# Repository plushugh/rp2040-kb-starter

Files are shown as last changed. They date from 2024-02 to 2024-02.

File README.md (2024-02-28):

# A Keyboard PCB Starter for the RaspberrySilicon RP2040 Microcontroller

## KiCad Requirements

I recommend KiCad version >= 8.0, and make sure you install the
[kiswitch](https://github.com/kiswitch/kiswitch) plugin (Version 2.4)
from the `Plugin and Content Manager`

I also recommend installing the kbplacer plugin for easy alignment of switch footprints

## Credits

Inspired by [Sleepdealr/RP2040-designguide](https://github.com/Sleepdealr/RP2040-designguide?tab=readme-ov-file)

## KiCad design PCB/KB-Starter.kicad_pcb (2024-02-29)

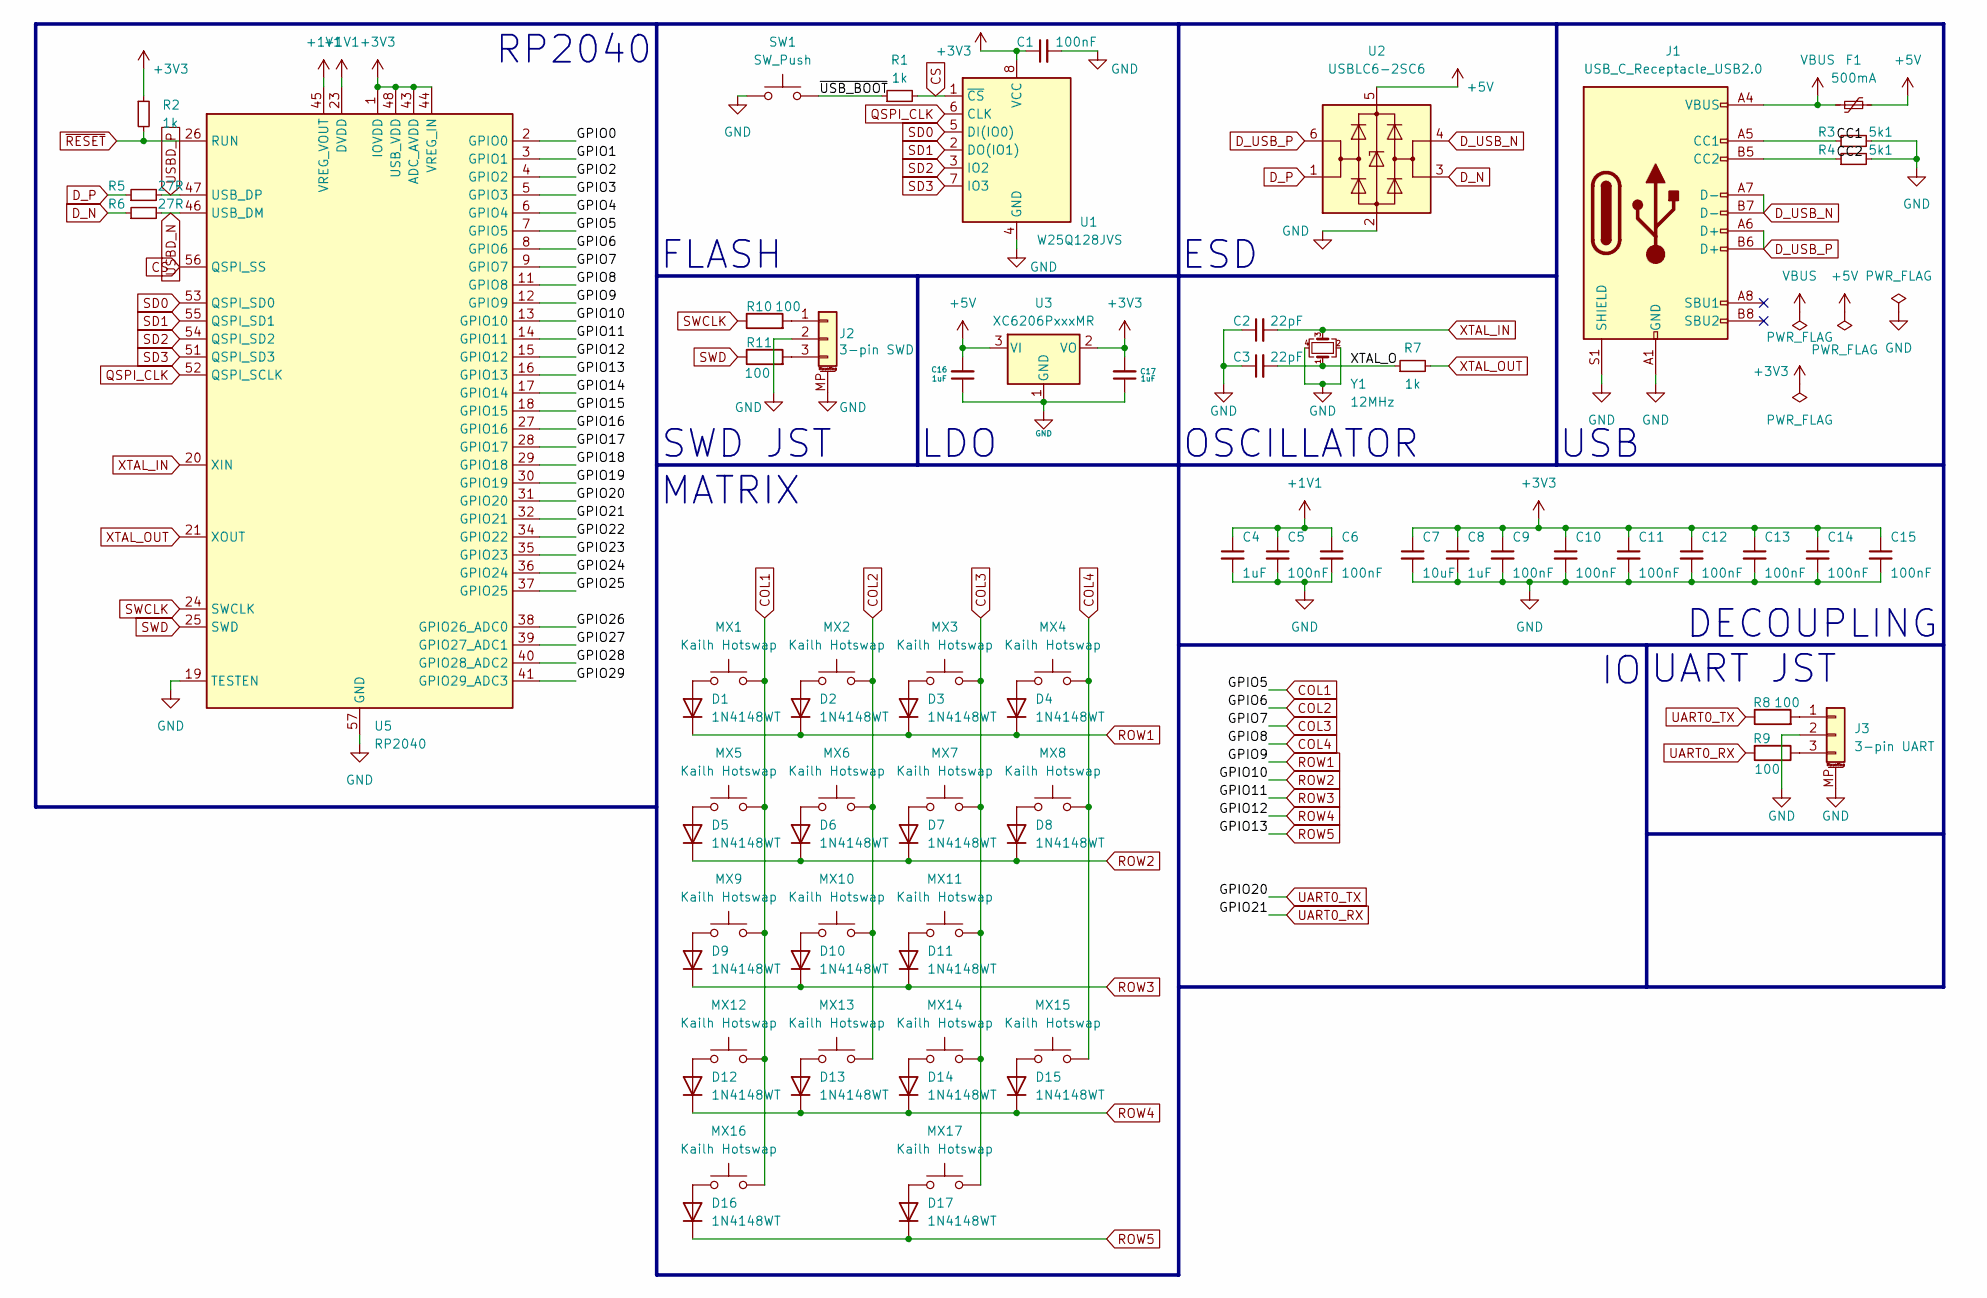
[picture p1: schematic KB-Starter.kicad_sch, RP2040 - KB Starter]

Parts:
C1, C5, C6, C9, C10, C11, C12, C13, C14, C15: 100nF; C_0402_1005Metric; LCSC C1525
C2, C3: 22pF; C_0402_1005Metric; LCSC C1555
C4, C8, C16, C17: 1uF; C_0402_1005Metric; LCSC C52923
C7: 10uF; C_0402_1005Metric; LCSC C15525
D1, D2, D3, D4, D5, D6, D7, D8, D9, D10, D11, D12, D13, D14, D15, D16, D17: 1N4148WT; D_SOD-523; LCSC C727112
F1: 500mA; Fuse_1206_3216Metric; LCSC C70076
J1: USB_C_Receptacle_USB2.0; USB_C_Receptacle_HRO_TYPE-C-31-M-12; LCSC C165948
J2: 3-pin SWD; JST_SH_BM03B-SRSS-TB_1x03-1MP_P1.00mm_Vertical
J3: 3-pin UART; JST_SH_BM03B-SRSS-TB_1x03-1MP_P1.00mm_Vertical
MX1, MX2, MX3, MX4, MX5, MX6, MX7, MX8, MX9, MX10, MX11, MX12, MX13, MX14, MX15, MX16, MX17: Kailh Hotswap; SW_Hotswap_Kailh_MX_1.00u; LCSC C5156480
R1, R2, R7: 1k; R_0402_1005Metric; LCSC C11702
R3, R4: 5k1; R_0402_1005Metric; LCSC C25905
R5, R6: 27R; R_0603_1608Metric; LCSC C25190
R8, R9, R10, R11: 100; R_0603_1608Metric
SW1: SW_Push; SW_SPST_PTS810; LCSC C221896
U1: W25Q128JVS; SOIC-8_5.23x5.23mm_P1.27mm; LCSC C131025
U2: USBLC6-2SC6; SOT-23-6; LCSC C2827654
U3: XC6206PxxxMR; SOT-23-3; LCSC C5250982
U5: RP2040; QFN-56-1EP_7x7mm_P0.4mm_EP3.2x3.2mm; LCSC C2040
Y1: 12MHz; Crystal_SMD_3225-4Pin_3.2x2.5mm; LCSC C9002

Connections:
+1V1: C4.1, C5.1, C6.1, U5.23 (DVDD), U5.45 (VREG_VOUT), U5.50 (DVDD)
+3V3: C1.1, C7.1, C8.1, C9.1, C10.1, C11.1, C12.1, C13.1, C14.1, C15.1, C17.2, R2.1, U1.8 (VCC), U3.2 (VO), U5.1 (IOVDD), U5.10 (IOVDD), U5.22 (IOVDD), U5.33 (IOVDD), U5.42 (IOVDD), U5.43 (ADC_AVDD), U5.44 (VREG_IN), U5.48 (USB_VDD), U5.49 (IOVDD)
+5V: C16.2, F1.2, U2.5 (VBUS), U3.3 (VI)
/CC1: J1.A5 (CC1), R3.1
/CC2: J1.B5 (CC2), R4.1
/GPIO0: U5.2 (GPIO0)
/GPIO1: U5.3 (GPIO1)
/GPIO2: U5.4 (GPIO2)
/GPIO3: U5.5 (GPIO3)
/GPIO4: U5.6 (GPIO4)
/GPIO14: U5.17 (GPIO14)
/GPIO15: U5.18 (GPIO15)
/GPIO16: U5.27 (GPIO16)
/GPIO17: U5.28 (GPIO17)
/GPIO18: U5.29 (GPIO18)
/GPIO19: U5.30 (GPIO19)
/GPIO22: U5.34 (GPIO22)
/GPIO23: U5.35 (GPIO23)
/GPIO24: U5.36 (GPIO24)
/GPIO25: U5.37 (GPIO25)
/GPIO26: U5.38 (GPIO26_ADC0)
/GPIO27: U5.39 (GPIO27_ADC1)
/GPIO28: U5.40 (GPIO28_ADC2)
/GPIO29: U5.41 (GPIO29_ADC3)
/XTAL_O: C3.2, R7.1, Y1.1
/~USB_BOOT: R1.1, SW1.2
COL1: MX1.2, MX5.2, MX9.2, MX12.2, MX16.2, U5.7 (GPIO5)
COL2: MX2.2, MX6.2, MX10.2, MX13.2, U5.8 (GPIO6)
COL3: MX3.2, MX7.2, MX11.2, MX14.2, MX17.2, U5.9 (GPIO7)
COL4: MX4.2, MX8.2, MX15.2, U5.11 (GPIO8)
CS: R1.2, U1.1 (~CS), U5.56 (QSPI_SS)
D_N: R6.1, U2.3 (I/O2)
D_P: R5.1, U2.1 (I/O1)
D_USB_N: J1.A7 (D-), J1.B7 (D-), U2.4 (I/O2)
D_USB_P: J1.A6 (D+), J1.B6 (D+), U2.6 (I/O1)
GND: C1.2, C2.1, C3.1, C4.2, C5.2, C6.2, C7.2, C8.2, C9.2, C10.2, C11.2, C12.2, C13.2, C14.2, C15.2, C16.1, C17.1, J1.A1 (GND), J1.A12 (GND), J1.B1 (GND), J1.B12 (GND), J1.S1 (SHIELD), J2.2, J2.MP (MountPin), J3.2, J3.MP (MountPin), R3.2, R4.2, SW1.1, U1.4 (GND), U2.2 (GND), U3.1 (GND), U5.19 (TESTEN), U5.57 (GND), Y1.2, Y1.4
unnamed: D1.2 (A), MX1.1
unnamed: D2.2 (A), MX2.1
unnamed: D3.2 (A), MX3.1
unnamed: D4.2 (A), MX4.1
unnamed: D5.2 (A), MX5.1
unnamed: D6.2 (A), MX6.1
unnamed: D7.2 (A), MX7.1
unnamed: D8.2 (A), MX8.1
unnamed: D9.2 (A), MX9.1
unnamed: D10.2 (A), MX10.1
unnamed: D11.2 (A), MX11.1
unnamed: D12.2 (A), MX12.1
unnamed: D13.2 (A), MX13.1
unnamed: D14.2 (A), MX14.1
unnamed: D15.2 (A), MX15.1
unnamed: D16.2 (A), MX16.1
unnamed: D17.2 (A), MX17.1
unnamed: J2.1, R10.2
unnamed: J2.3, R11.2
unnamed: J3.1, R8.2
unnamed: J3.3, R9.1
QSPI_CLK: U1.6 (CLK), U5.52 (QSPI_SCLK)
ROW1: D1.1 (K), D2.1 (K), D3.1 (K), D4.1 (K), U5.12 (GPIO9)
ROW2: D5.1 (K), D6.1 (K), D7.1 (K), D8.1 (K), U5.13 (GPIO10)
ROW3: D9.1 (K), D10.1 (K), D11.1 (K), U5.14 (GPIO11)
ROW4: D12.1 (K), D13.1 (K), D14.1 (K), D15.1 (K), U5.15 (GPIO12)
ROW5: D16.1 (K), D17.1 (K), U5.16 (GPIO13)
SD0: U1.5 (DI(IO0)), U5.53 (QSPI_SD0)
SD1: U1.2 (DO(IO1)), U5.55 (QSPI_SD1)
SD2: U1.3 (IO2), U5.54 (QSPI_SD2)
SD3: U1.7 (IO3), U5.51 (QSPI_SD3)
SWCLK: R10.1, U5.24 (SWCLK)
SWD: R11.1, U5.25 (SWD)
UART0_RX: R9.2, U5.32 (GPIO21)
UART0_TX: R8.1, U5.31 (GPIO20)
USBD_N: R6.2, U5.46 (USB_DM)
USBD_P: R5.2, U5.47 (USB_DP)
VBUS: F1.1, J1.A4 (VBUS), J1.A9 (VBUS), J1.B4 (VBUS), J1.B9 (VBUS)
XTAL_IN: C2.2, U5.20 (XIN), Y1.3
XTAL_OUT: R7.2, U5.21 (XOUT)
~RESET: R2.2, U5.26 (RUN)

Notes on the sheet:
MATRIX
ESD
UART JST
DECOUPLING
OSCILLATOR
USB
LDO
SWD JST
RP2040
FLASH

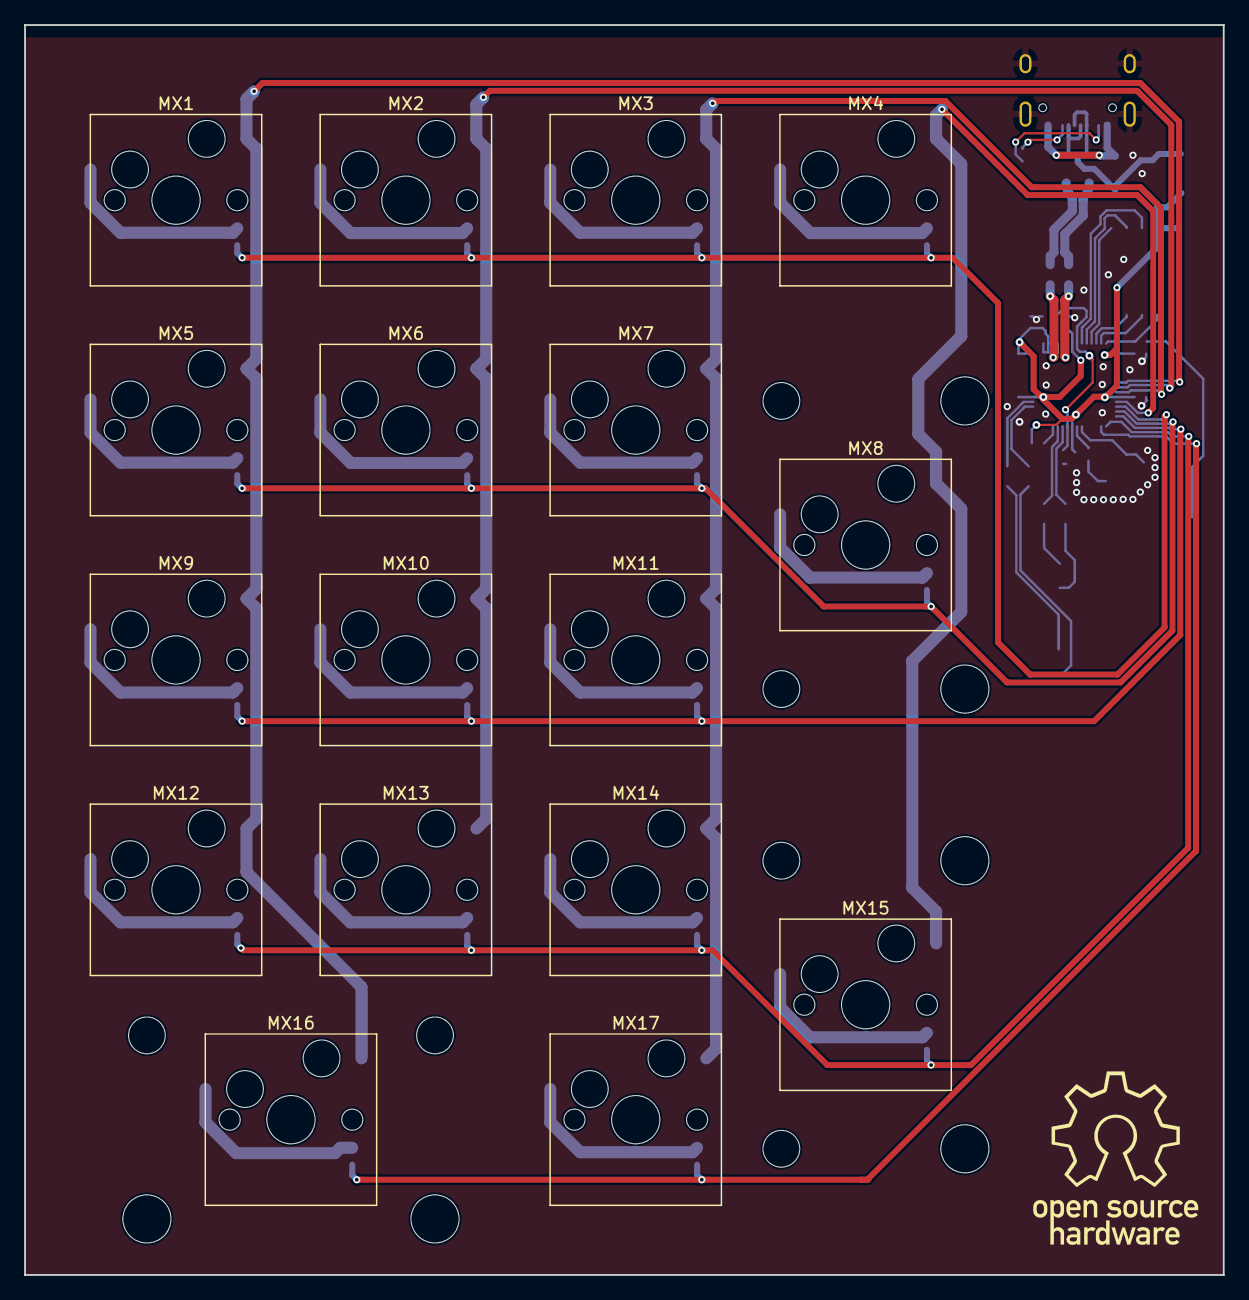
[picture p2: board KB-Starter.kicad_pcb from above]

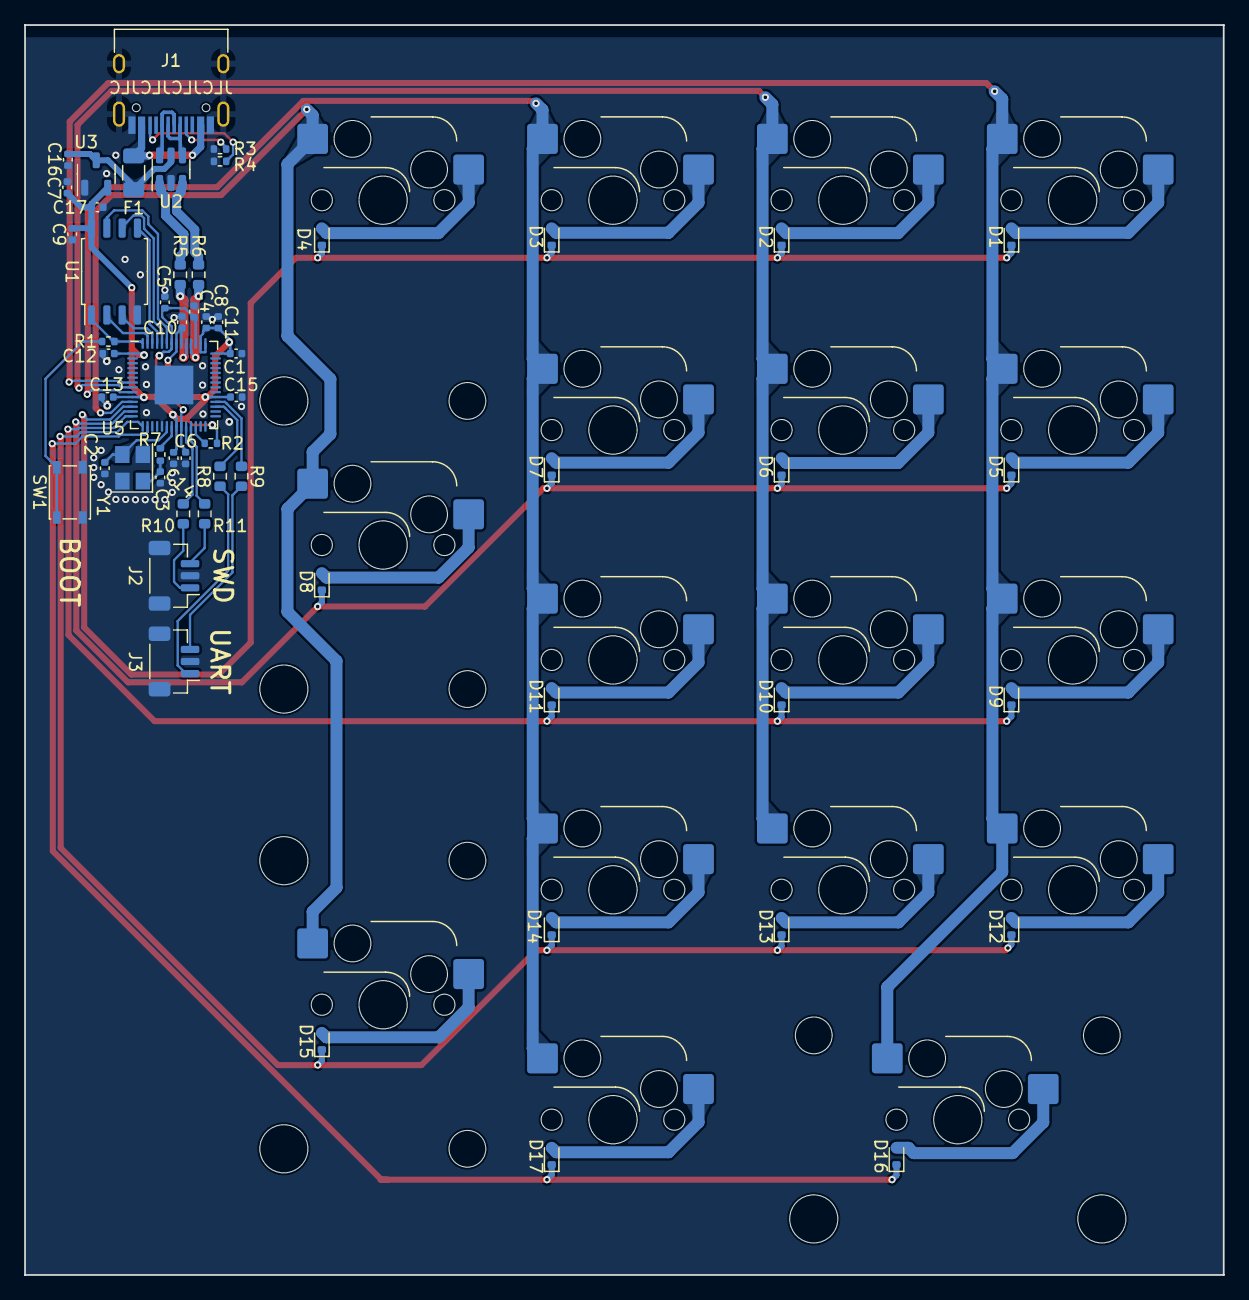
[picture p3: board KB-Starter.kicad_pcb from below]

Board: 2 copper layers, 99.3 x 103.6 mm, 75 parts (55 on the bottom side), 58 nets.

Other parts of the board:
STAB1, STAB2, STAB3: Stabilizer_Cherry_MX_2.00u

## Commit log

2024-02-13 init: basic mcu setup
    [KB-Starter.kicad_pcb, KB-Starter.kicad_sch]
2024-02-14 fix: USB data line impedance and length
    [KB-Starter.kicad_pcb]
2024-02-14 fix: reduce via-in-pads
    [KB-Starter.kicad_pcb]
2024-02-14 fix+feat: matrix fix + touchup
    [KB-Starter.kicad_pcb, KB-Starter.kicad_sch]
2024-02-14 feat: stabs
    [KB-Starter.kicad_pcb]
2024-02-14 fix: old footprints
    [KB-Starter.kicad_pcb]
2024-02-28 add missing 3d models, cleanup for KiCad 8, swd
    [KB-Starter.kicad_pcb, KB-Starter.kicad_sch]
2024-02-28 chore: bump README KiCad ver requirements
2024-02-29 feat: cleanup, graphics, JLCPCB DRU
    [KB-Starter.kicad_pcb, KB-Starter.kicad_sch]
